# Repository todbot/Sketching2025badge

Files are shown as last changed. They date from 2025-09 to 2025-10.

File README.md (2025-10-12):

# Sketching2025badge

Badge for Sketching in Hardware 2025

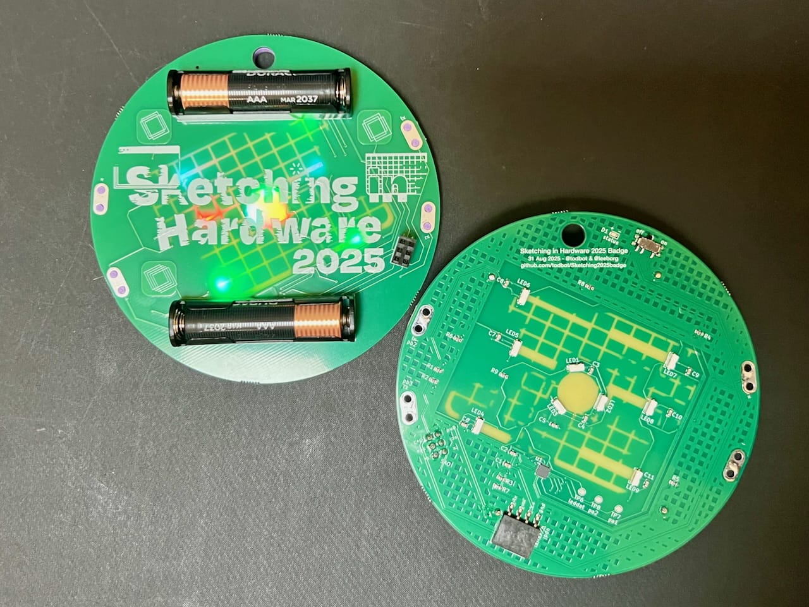
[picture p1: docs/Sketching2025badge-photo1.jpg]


sketching2025-badge-demoish-crop

# Features

- Three (3) capacitive touch pads
- Nine (9) "Neopixel"-compatible side-light RGB LEDs that shine through the back
- Four (4) sewable connectors: V+, Gnd, TX (PB2), and RX (PB3)
- One status LED on back of board
- Standard SAO pinout w/ I2C. Spare GPIO lines wired to UART TX/RX
- ATtiny816-based, same as [seesaw boards](https://learn.adafruit.com/adafruit-attiny817-seesaw)
- Easy compilation using standard Ardiuno toolchain and [megaTinyCore](https://github.com/SpenceKonde/megaTinyCore)
- Programmable with UDPI with a [USB-Serial adapter](https://amzn.to/3IKpMry)
- Uses modified [TouchyTouch](https://github.com/todbot/TouchyTouch) captouch library, included

# ATtiny816 pins used

| Use | GPIO | Arduino pin |
|---|---|---|
| Status LED | PB4 | 5 |
| Neopixel LEDs | PC2 | 12 |
| Touch pad 0 | PA6 | 0 |
| Touch pad 1 | PA5 | 1 |
| Touch pad 2 | PA4 | 2 |
| SAO I2C SCL | PB0 | 9 |
| SAO I2C SDA | PB1 | 8 |
| Sew / SAO UART TX | PB2 | 7 |
| Sew / SAO UART RX | PB3 | 6 |

# Reprogramming the badge

The default firmware is a fun little demo. But you can extend or replace it.

For details see [docs/firmware-install.md](docs/firmware-install.md)

But basically:
- Open up Arduino, add http://drazzy.com/package_drazzy.com_index.json
to the Board Manager URLs in Settings.
- Load "firmware/Sketching2025badge_attiny816/Sketching2025badge_attiny816.ino"
- Set the chip & programmer settings as in firmware-install.md
- Upload code with "Sketch" -> "Upload Using Programmer"

# Protective "Backer"

Since the LEDs and MCU on the back don't have the protection of the battery
holders as standoffs, a 3d-printed "backer" is included with the badge.
It snaps onto the badge using the sewable holes.
It can be removed by lifting it out, if you want to sew the badge down or
otherwise use the sewable holes.

See the "enclosure" directory for STEP/STL to print your own.

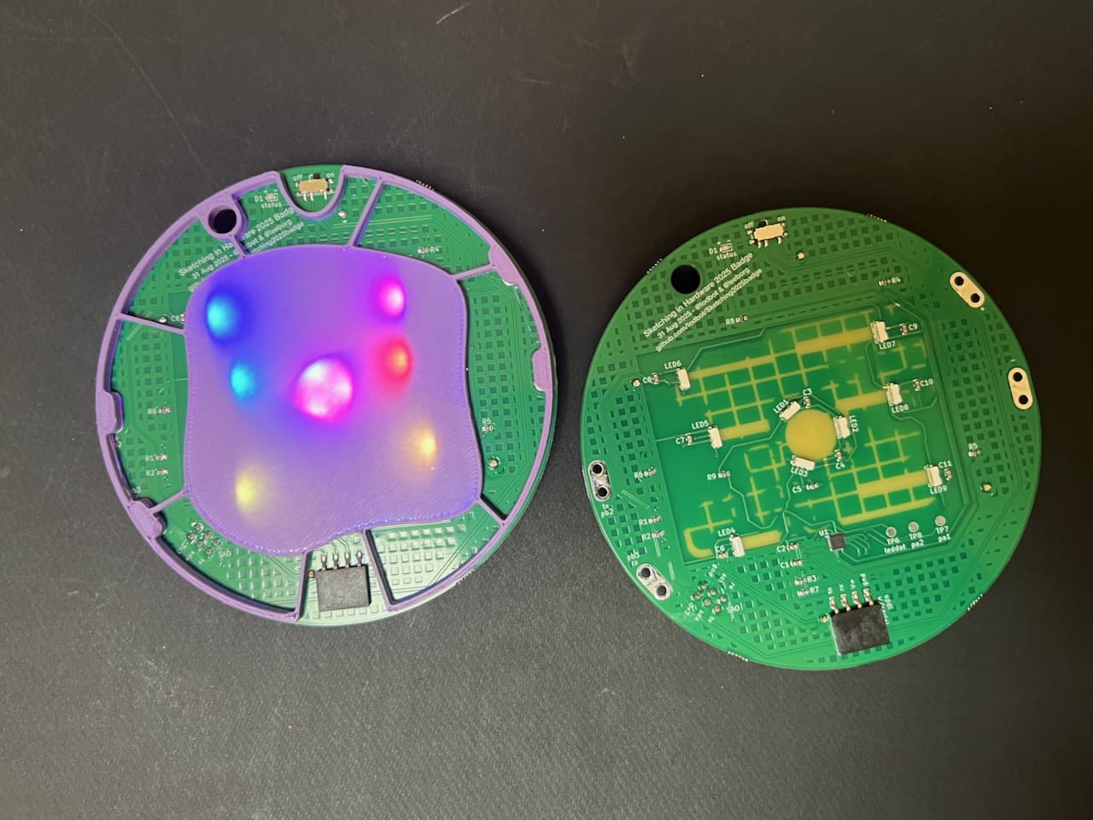
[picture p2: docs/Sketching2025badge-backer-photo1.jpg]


# Demos

* 30Aug2025 - Prototyp0 PCBA w/ batts on face, from JLC (with oops mask hole in center)

  https://github.com/user-attachments/assets/092c7233-f480-4e2a-861c-cc95c8bd24c3

# Renders

* 1 Oct 2025 - production version

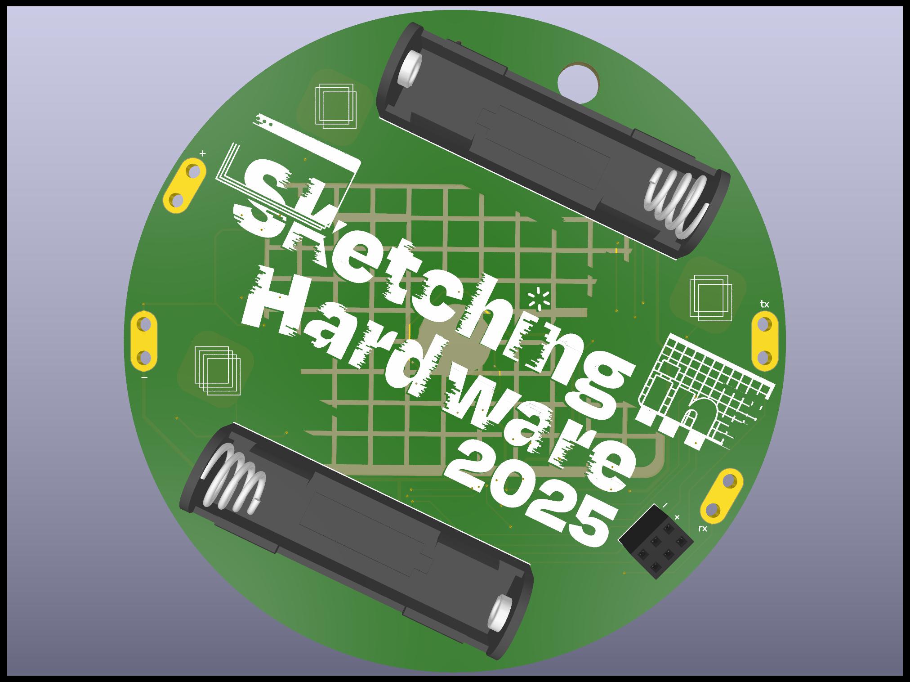
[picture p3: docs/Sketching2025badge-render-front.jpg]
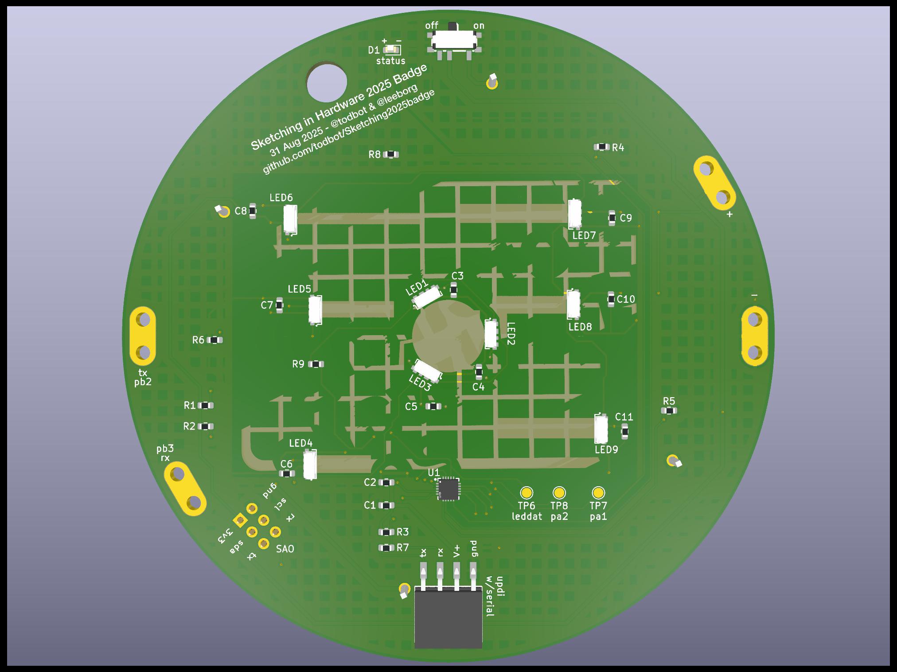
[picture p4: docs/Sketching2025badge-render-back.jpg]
  

* 16Aug2025 - Render0 - refaced TouchWheelSAO, basic graphics layout on 100mm (4") circular PCB, all components on back, routing incomplete

  https://github.com/user-attachments/assets/017a1953-9797-4b04-9c11-582e099e5368

* 16Aug2026 - Render0a - same as above, but with AAA holders on top

  https://github.com/user-attachments/assets/b0e8170d-4cca-4846-9cb0-e9c19dae7c72

# Schematic

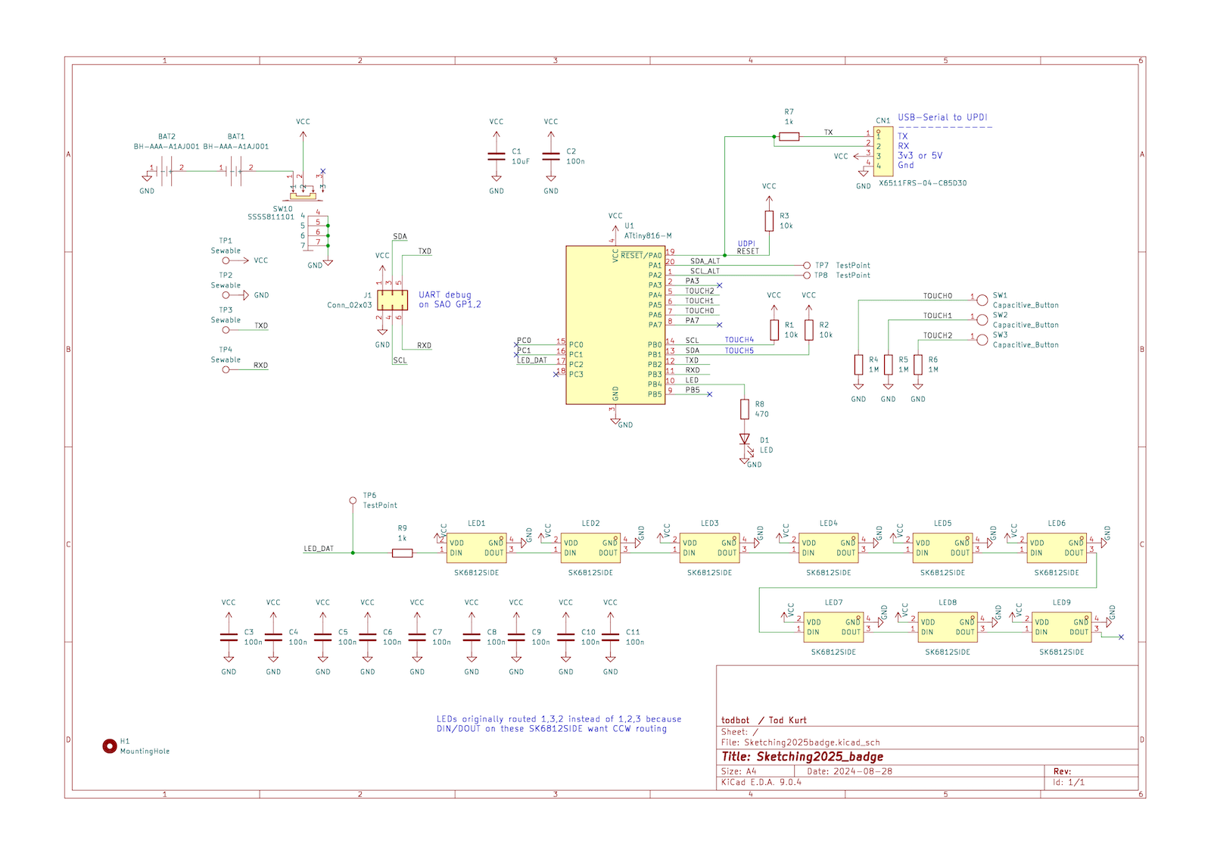
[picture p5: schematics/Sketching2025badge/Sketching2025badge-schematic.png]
Sketching 2025 badge schematic


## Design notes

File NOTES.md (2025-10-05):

## Notes:

* 1 Oct 2025 - 48 badges mailed to Paris
  - 20 had backers
  - still printing remainders

* 29 Sep 2025 - Design & print protective "backer"
  - Design for "fast" printing (~30 min each on my old Prusa mk2.5s)
  - Start batch 3D printing

* 29 Sep 2025 - "final" firmware cutoff
  - batch program begin
  - programmed 50 production boards
  - all boards passed basic programming & lighting test

* 23 Sep 2025 - Badge PCBAs received from JLC
  - delivered from JLC via UPS
  - badge final assembly: hand solder battery holder & SAO header

* 11 Sep 2025 - PCBAs ordered
  - PCBway wanted $1k for badges, even with sponsorship
  - Ordered JLCPCB instead $344 (inc. shipping & tariffs)

* 30 Aug 2025 - tested prototype0
  - All parts seem functional, both at 5V of programmer & 3V of AA batteries
  - Idle current: 15 mA at 10 MHz, 10 mA at 8 MHz
  - Don't set to 4 MHz, it doesn't work. LEDs go all white (drawing 300mA)
  - To-Do:
    - edit light mask polygons on back to be wider
    - move LEDs out from under battery holder
    - change UDPI prog footprint to female SMD RA header socket

* 24 Aug 2025 - prototype0 sent to JLC, with "21 Aug 2025" datestamp

* 16 Aug 2025 - basic graphics import test, got okay from leeborg

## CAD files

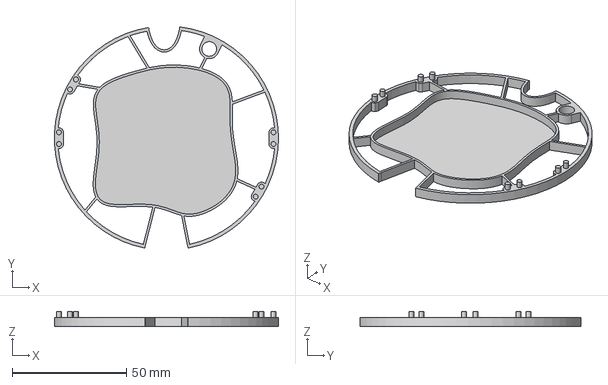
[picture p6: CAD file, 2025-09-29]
enclosure/Sketching2025badge_backing.step
97.9 x 96.7 x 6.50 mm

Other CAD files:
enclosure/Sketching2025badge_backing.stl

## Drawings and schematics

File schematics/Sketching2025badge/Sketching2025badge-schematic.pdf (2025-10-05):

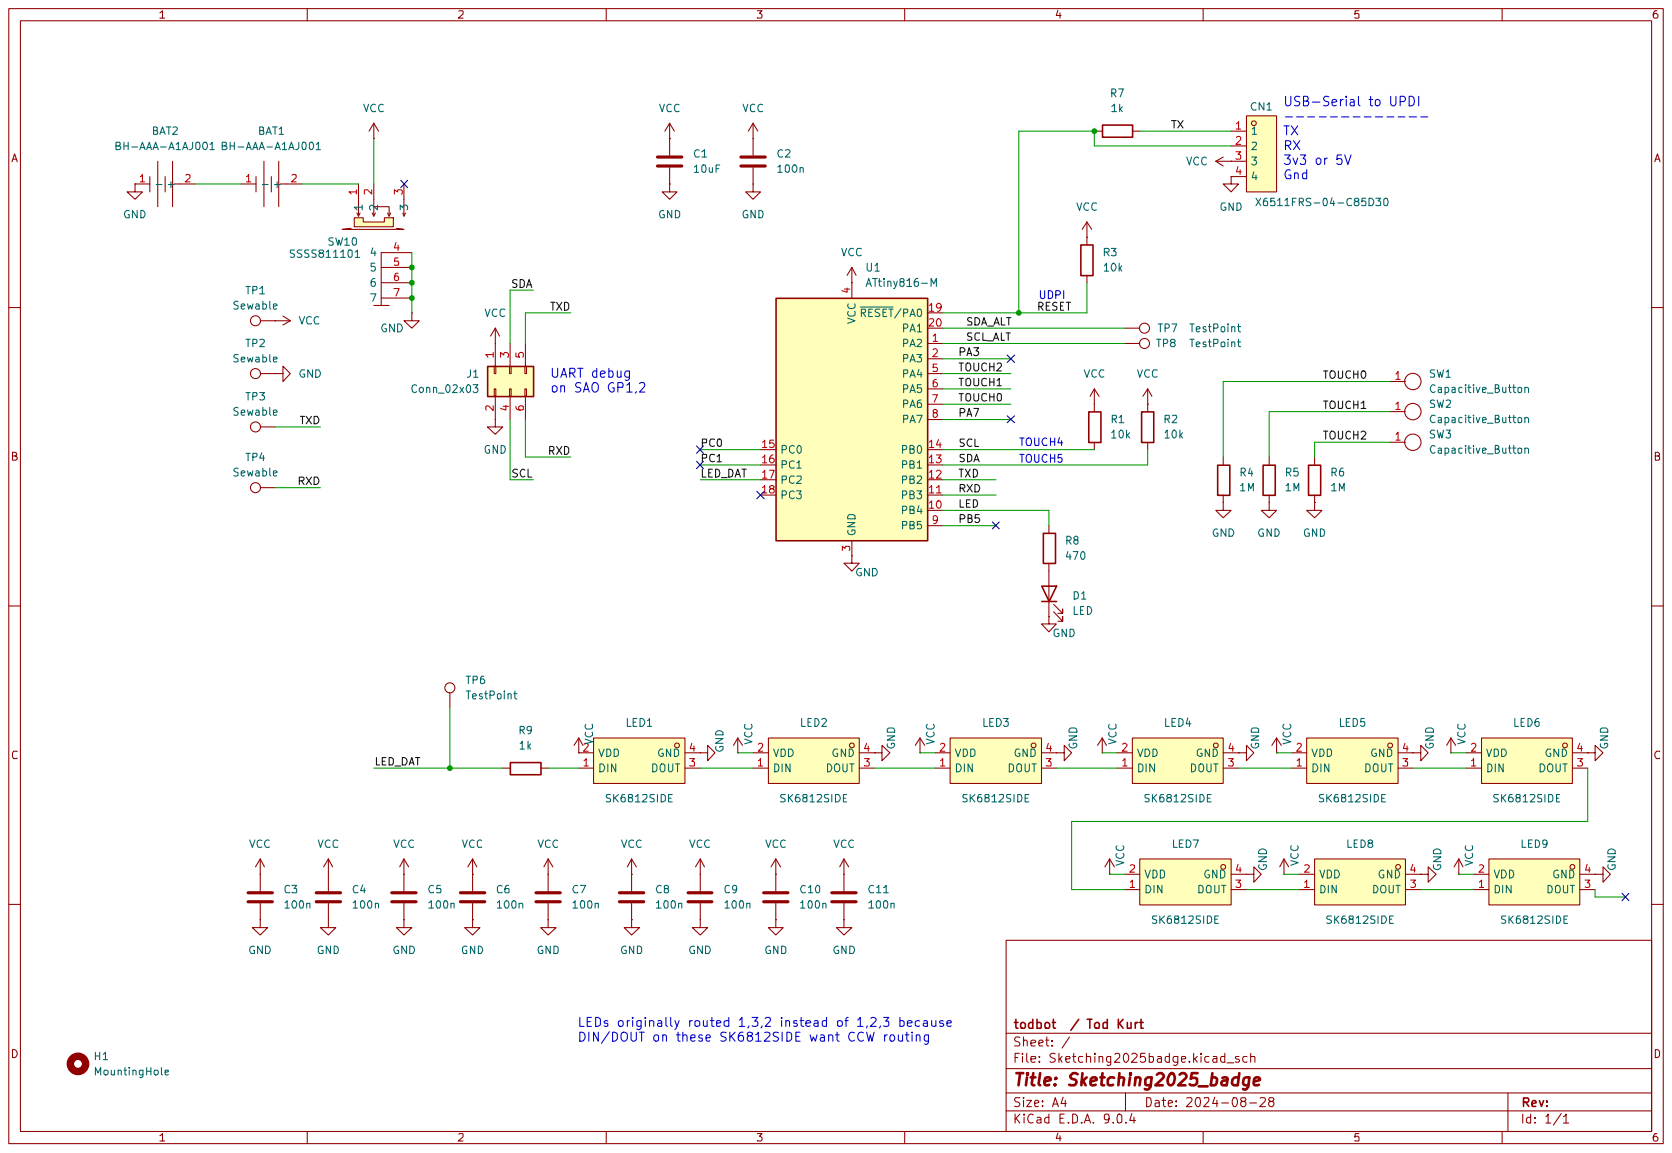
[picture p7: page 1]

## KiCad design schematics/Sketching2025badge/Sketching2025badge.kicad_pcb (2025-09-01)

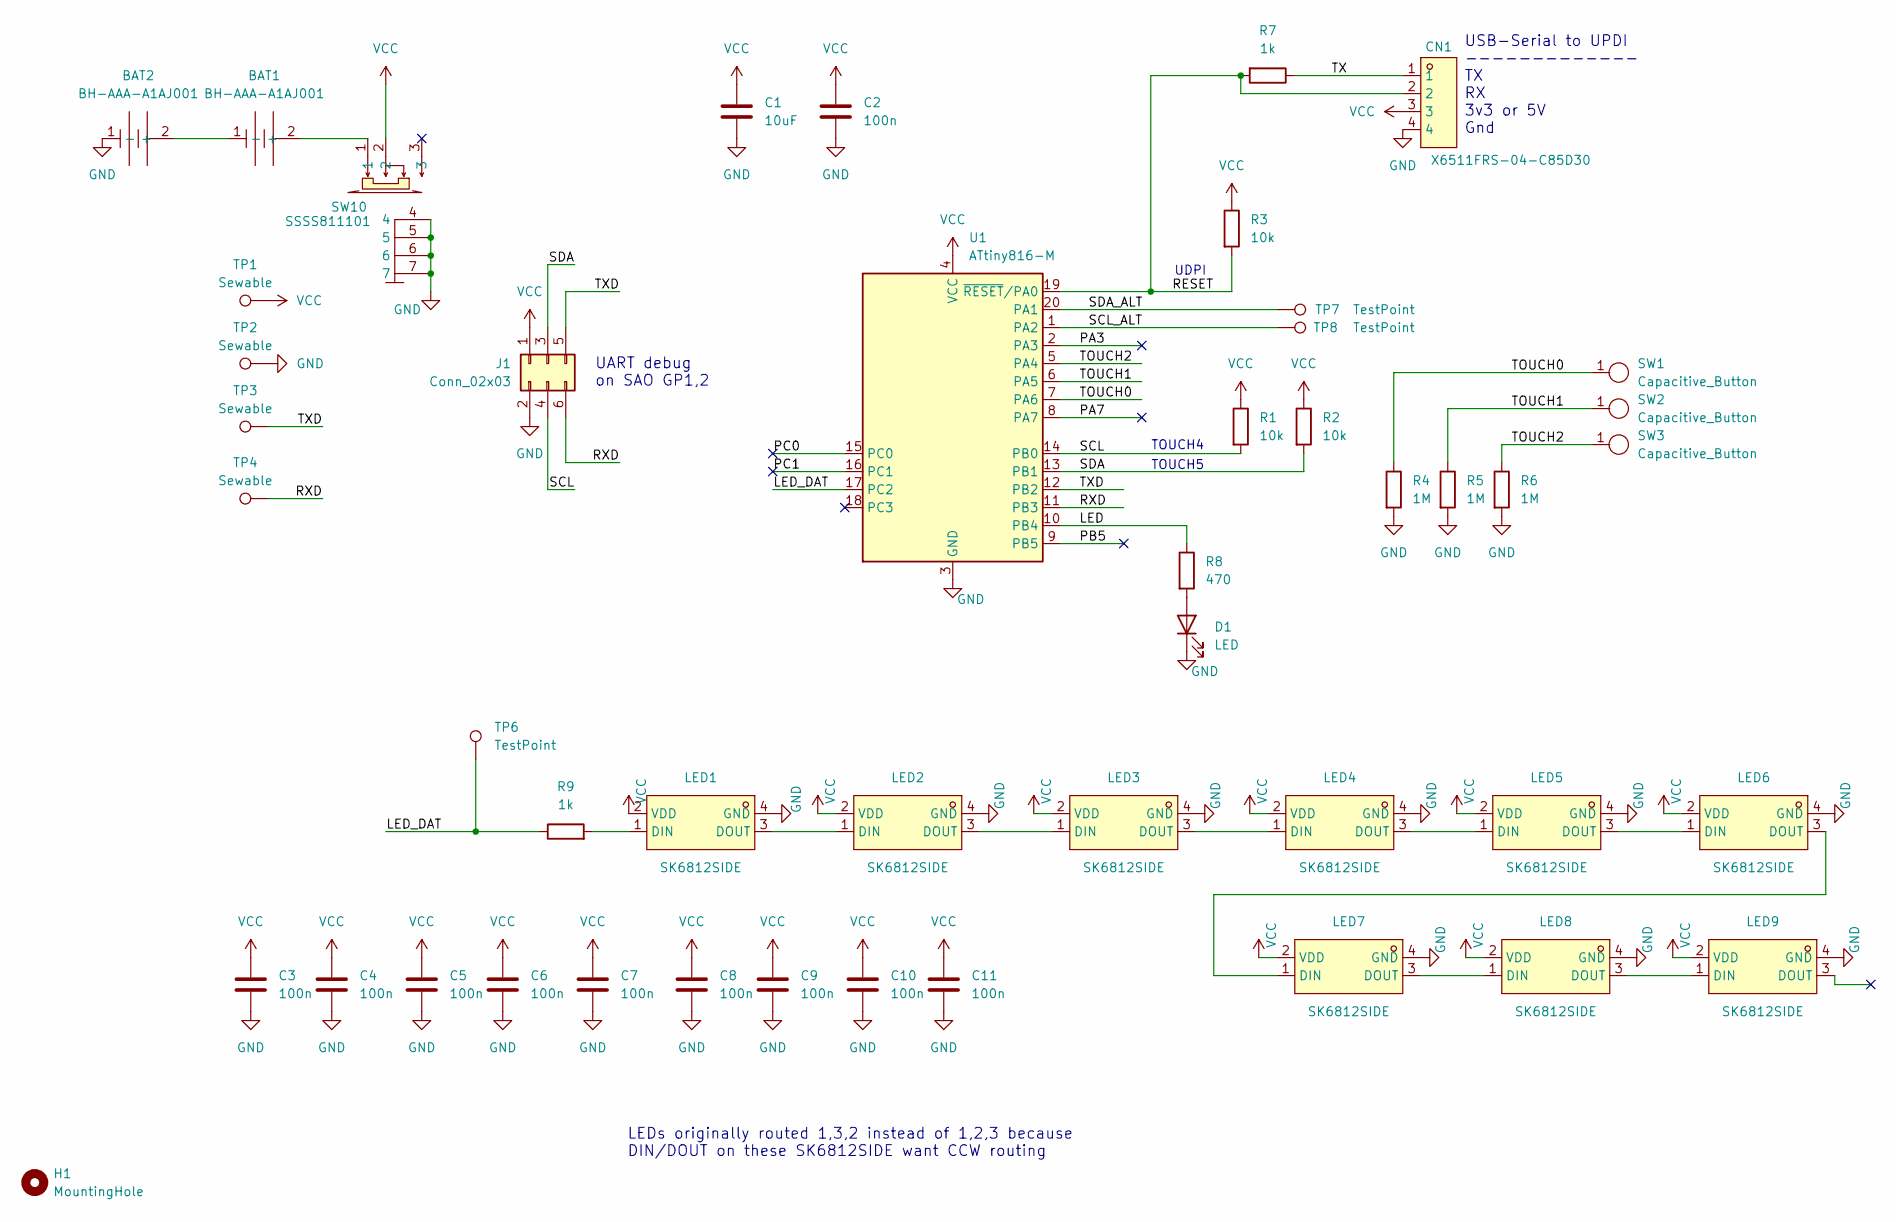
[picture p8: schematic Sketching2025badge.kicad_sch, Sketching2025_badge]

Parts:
BAT1, BAT2: BH-AAA-A1AJ001; BAT-TH_BH-AAA-A1AJ001; LCSC Part C5290189
C1: 10uF; R_0603_1608Metric; LCSC Part C434425
C2, C3, C4, C5, C6, C7, C8, C9, C10, C11: 100n; R_0603_1608Metric; LCSC Part C1590
CN1: X6511FRS-04-C85D30; HDR-SMD_4P-P2.54-H-F; LCSC Part C5142237
D1: LED; LED_0603_1608Metric; LCSC Part C434425
H1: MountingHole; MountingHole_6.4mm_M6
J1: Conn_02x03; PinSocket_2x03_P2.54mm_Vertical; Part Number LL1009-2A, 2.54MM 2*3PIN HEADER,LENGTH=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; LCSC Part C541853
LED1, LED2, LED3, LED4, LED5, LED6, LED7, LED8, LED9: SK6812SIDE; LED-SMD_4P-L4.0-W1.6-L; LCSC Part C5378721
R1, R2, R3: 10k; R_0603_1608Metric
R4, R5, R6: 1M; R_0603_1608Metric
R7, R9: 1k; R_0603_1608Metric
R8: 470; R_0603_1608Metric
SW1, SW2, SW3: Capacitive_Button; Pad-CapTouch-10mm-roundrect-nosilk
SW10: SSSS811101; SW-SMD_SSSS811101; LCSC Part C109335
TP1, TP2, TP3, TP4: Sewable; Lilypad-BUTTONHOLE
TP6, TP7, TP8: TestPoint; TestPoint_Pad_D1.5mm
U1: ATtiny816-M; UQFN-20_L3.0-W3.0-P0.40-BL-EP1.7; LCSC Part C2052778

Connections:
/LED: R8.1, U1.10 (PB4)
/LED_DAT: R9.1, TP6.1, U1.17 (PC2)
/PA3: U1.2 (PA3)
/PA7: U1.8 (PA7)
/PB5: U1.9 (PB5)
/PC0: U1.15 (PC0)
/PC1: U1.16 (PC1)
/RESET: CN1.2, R3.2, R7.2, U1.19 (~RESET/PA0)
/RXD: J1.6 (GND), TP4.1, U1.11 (PB3)
/SCL: J1.4 (GND), R1.2, U1.14 (PB0)
/SCL_ALT: TP8.1, U1.1 (PA2)
/SDA: J1.3 (GND), R2.2, U1.13 (PB1)
/SDA_ALT: TP7.1, U1.20 (PA1)
/TOUCH0: R4.1, SW1.1 (A), U1.7 (PA6)
/TOUCH1: R5.1, SW2.1 (A), U1.6 (PA5)
/TOUCH2: R6.1, SW3.1 (A), U1.5 (PA4)
/TX: CN1.1, R7.1
/TXD: J1.5 (GND), TP3.1, U1.12 (PB2)
GND: BAT2.1 (-), C1.2, C2.2, C3.2, C4.2, C5.2, C6.2, C7.2, C8.2, C9.2, C10.2, C11.2, CN1.4, D1.1 (K), J1.2 (+12V), LED1.4 (GND), LED2.4 (GND), LED3.4 (GND), LED4.4 (GND), LED5.4 (GND), LED6.4 (GND), LED7.4 (GND), LED8.4 (GND), LED9.4 (GND), R4.2, R5.2, R6.2, SW10.4, SW10.5, SW10.6, SW10.7, TP2.1, U1.3 (GND), U1.21 (GND)
unnamed: BAT1.2 (+), SW10.1
unnamed: BAT1.1 (-), BAT2.2 (+)
unnamed: D1.2 (A), R8.2
unnamed: LED1.1 (DIN), R9.2
unnamed: LED1.3 (DOUT), LED2.1 (DIN)
unnamed: LED2.3 (DOUT), LED3.1 (DIN)
unnamed: LED3.3 (DOUT), LED4.1 (DIN)
unnamed: LED4.3 (DOUT), LED5.1 (DIN)
unnamed: LED5.3 (DOUT), LED6.1 (DIN)
unnamed: LED6.3 (DOUT), LED7.1 (DIN)
unnamed: LED7.3 (DOUT), LED8.1 (DIN)
unnamed: LED8.3 (DOUT), LED9.1 (DIN)
VCC: C1.1, C2.1, C3.1, C4.1, C5.1, C6.1, C7.1, C8.1, C9.1, C10.1, C11.1, CN1.3, J1.1 (+12V), LED1.2 (VDD), LED2.2 (VDD), LED3.2 (VDD), LED4.2 (VDD), LED5.2 (VDD), LED6.2 (VDD), LED7.2 (VDD), LED8.2 (VDD), LED9.2 (VDD), R1.1, R2.1, R3.1, SW10.2, TP1.1, U1.4 (VCC)

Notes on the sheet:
LEDs originally routed 1,3,2 instead of 1,2,3 because DIN/DOUT on these SK6812SIDE want CCW routing
TOUCH5
TOUCH4
UART debug on SAO GP1,2
USB-Serial to UPDI ------------- TX RX 3v3 or 5V Gnd
UDPI

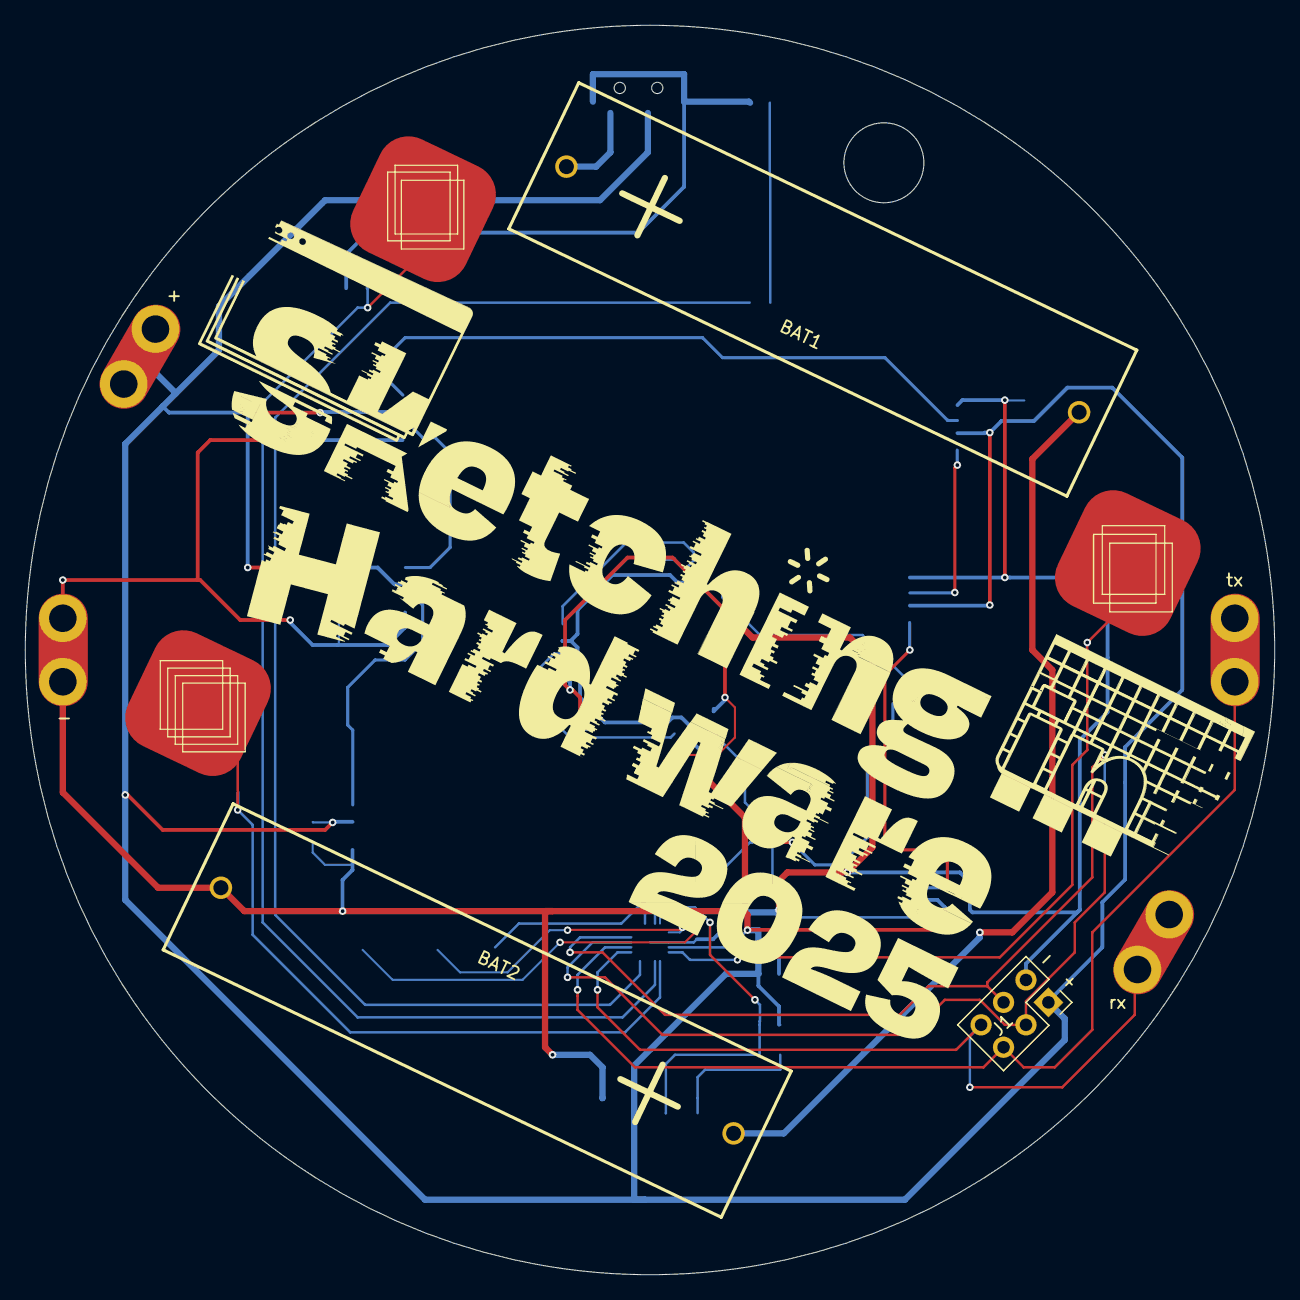
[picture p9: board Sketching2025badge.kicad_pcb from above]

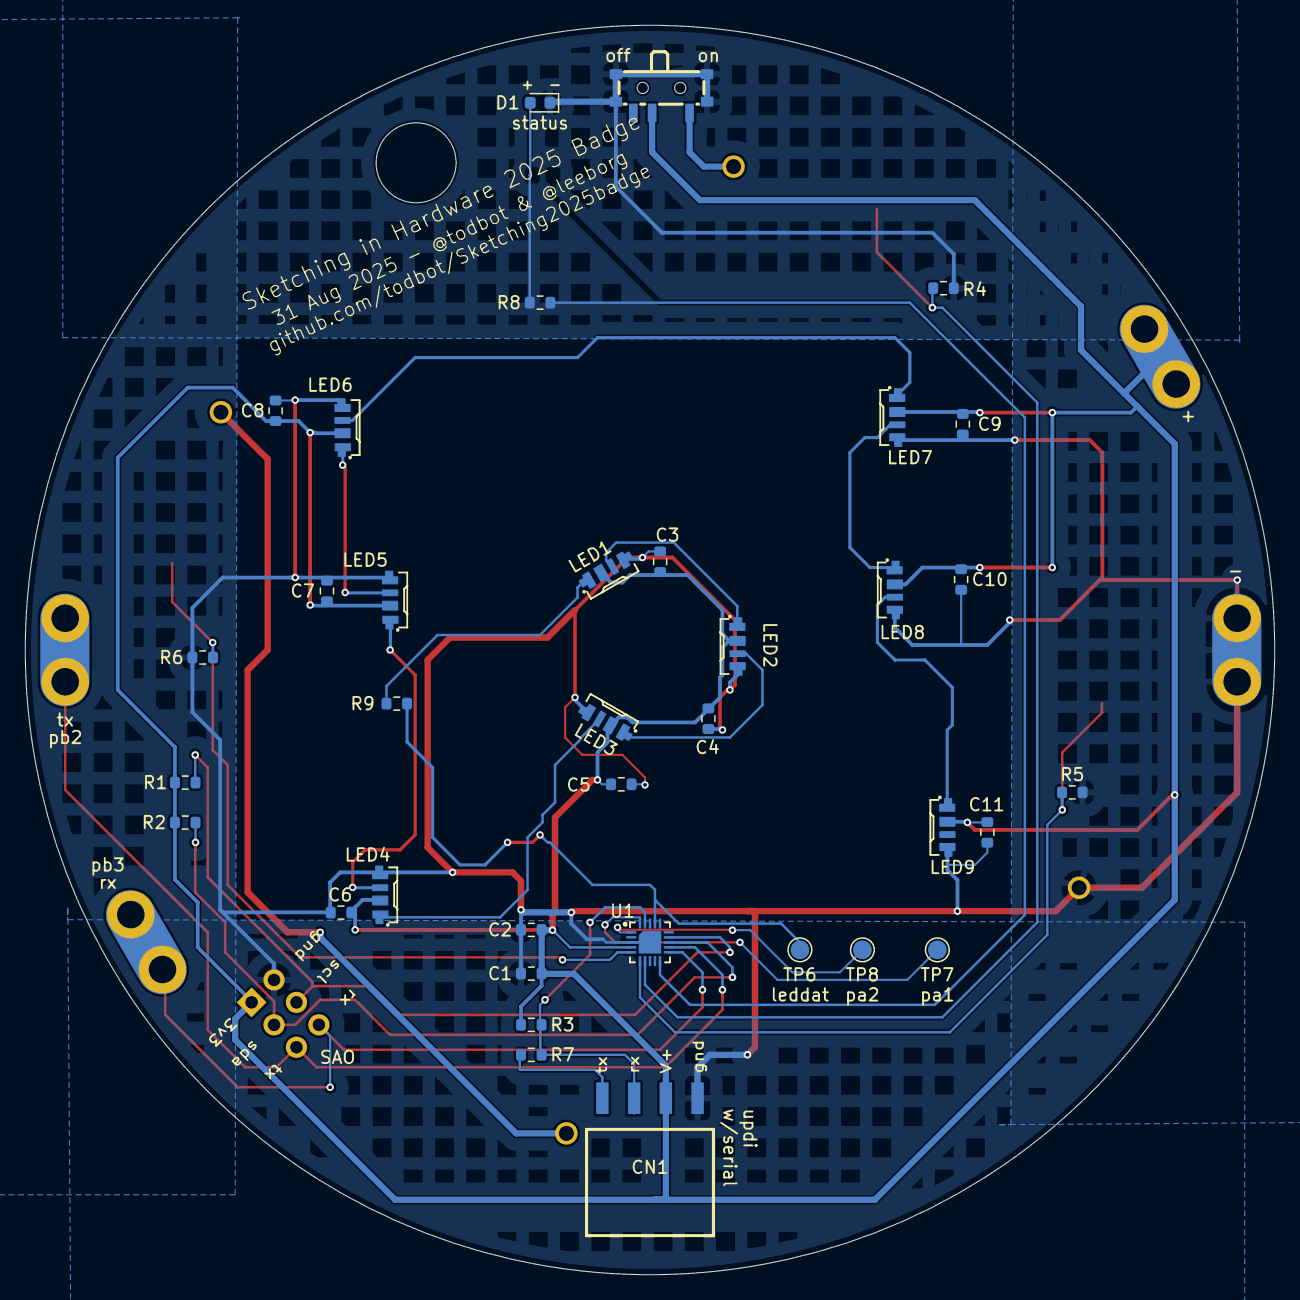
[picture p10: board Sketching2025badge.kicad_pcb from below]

Board: 2 copper layers, 100.0 x 100.0 mm, 47 parts (40 on the bottom side), 27 nets.

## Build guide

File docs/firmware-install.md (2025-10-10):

# Installing firmware on Sketching2025badge board

Use any Windows, MacOS, Linux, RaspberryPi host with USB-to-serial adapter.

## Hardware prep

The Sketching2025badge board has the UPDI programming port brought out as a 4-pin
SMD header, which a 4-pin pin header can be soldered, or a 4-pin 0.1" spacing
pogo-pin jig clamp can be attached.

The pins on the TouchWheelSAO board are laid out for use with a
[USB-to-serial adapter wired as a UPDI programmer](https://learn.adafruit.com/adafruit-attiny817-seesaw/advanced-reprogramming-with-updi)
but you can also use a standard UPDI programmer too.

Here is what a programmer setup could look like, using:
* [cheap USB-to-serial dongle](https://amzn.to/47sMaxz)
* [Pogo pin probe clip](https://www.digikey.com/short/3c99n5p9)

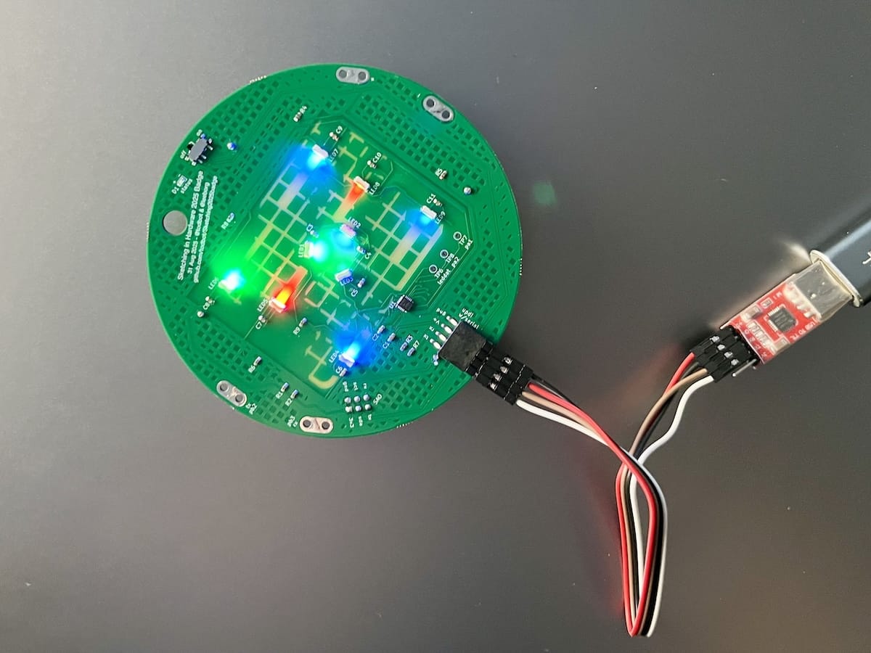
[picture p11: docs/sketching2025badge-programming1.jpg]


## Software, Compiling, Uploading

### GUI IDE install

If installing with the Arduino GUI, you need to install the latest Arduino IDE 
from [arduino.cc/en/software/](https://www.arduino.cc/en/software/#ide).

The badge is based on the AVR ATtiny816 chip.  
This is supported by the [megaTInyCore](https://github.com/SpenceKonde/megaTinyCore) 
In the Arduino IDE, add this core by going to Settings / Additional Board Manager URLs and 
add `http://drazzy.com/package_drazzy.com_index.json` to the list. 
Then in Boards Manager, add "megaTinyCore".

Pick the board type in Tools / Board as "megaTinyCore" -> "ATtiny3226/3216/../816/../406"

In the Tools menu, set the chip parameters as:

- Chip: "ATtiny816"
- Clock: "8 MHz internal"
- Printf: "minimal"
- Programmer: "Serial UDPI - SLOW 57600" or "Serial UDPI - 230400"
- (leave everything else as default)

When uploading, use "Upload Using Programmer" instead of the normal "Upload".

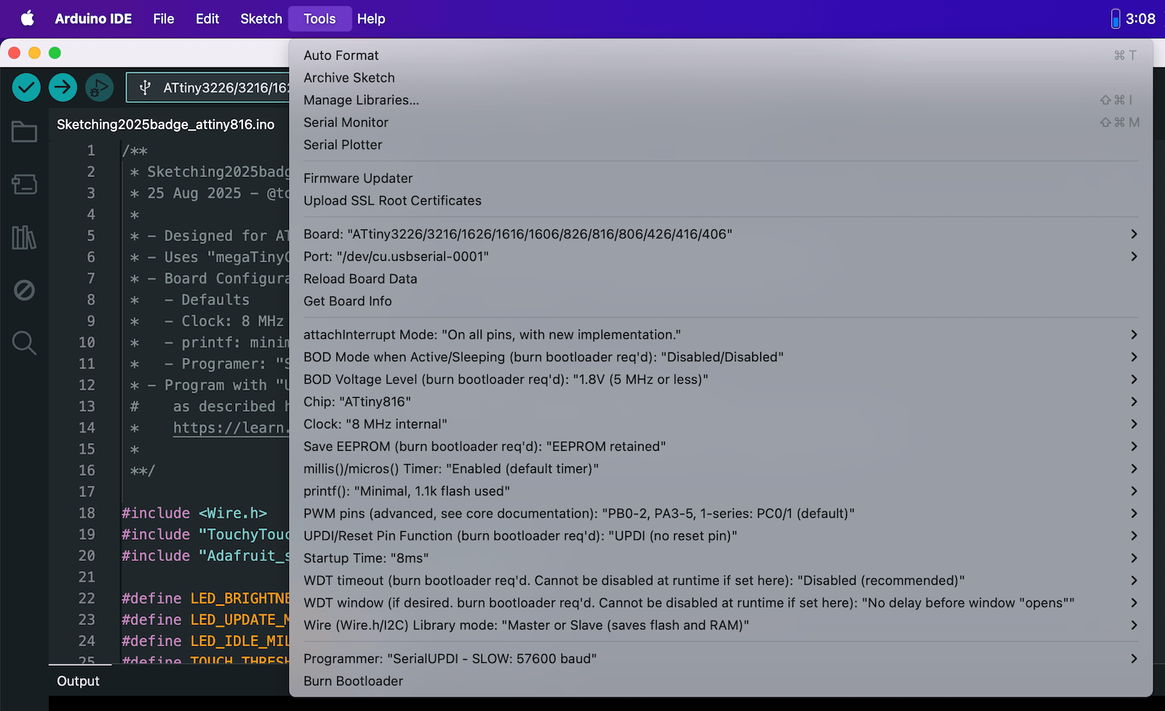
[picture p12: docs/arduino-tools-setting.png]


### Arduino-CLI install

Instead of installing the Arduino IDE, we can also use [arduino-cli](https://arduino.github.io/arduino-cli/1.0/)

#### Install arduino-cli

The [arduino-cli install page](https://arduino.github.io/arduino-cli/1.0/installation/#latest-release)
has pre-built binaries for common platforms.  And if on MacOS, you can do `brew install arduino-cli`

#### Install megatinycore 

The badge uses the ATtiny816 chip.  This is supported by the MegaTinyAVR core. 

```sh
arduino-cli core install megatinycore:megaavr  --additional-urls https://drazzy.com/package_drazzy.com_index.json
 ```

#### Show some details on the core (optional):

```sh
arduino-cli board details -b megaTinyCore:megaavr:atxy6
```

#### Compile:

```sh
arduino-cli compile --verbose --fqbn megaTinyCore:megaavr:atxy6:chip=816,printf=minimal,clock=8internal \
            --build-path=$(pwd)/build Sketching2025badge_attiny816
```

#### Upload

```sh
arduino-cli upload --verbose --fqbn megaTinyCore:megaavr:atxy6:chip=816  \
            --port /dev/ttyUSB0 --programmer serialupdi57k  \
            --input-dir ./build

```

#### Shell script for batch programming

Also see `firmware/batch_build_program.sh`

```sh
#!/bin/bash

PORT=/dev/ttyUSB0
HEX_FILE=./build/Sketching2025badge_attiny816.ino.hex

while [ 1 ] ; do
  read -rsn1 -p"Press any key program firmware"; echo
  arduino-cli upload --verbose --fqbn megaTinyCore:megaavr:atxy6:chip=816  \
              --port $PORT --programmer serialupdi57k  \
              --input-file=$HEX_FILE
  echo "--------------------"
done

```

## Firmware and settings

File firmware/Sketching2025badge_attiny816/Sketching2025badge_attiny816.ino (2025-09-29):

/**
 * Sketching2025badge_attiny816.ino -- 
 * 25 Aug 2025 - @todbot / Tod Kurt
 * 
 * - Designed for ATtiny816
 * - Uses "megaTinyCore" Arduino core: https://github.com/SpenceKonde/megaTinyCore/
 * - Board Configuration in Tools:
 *   - Defaults
 *   - Clock: 8 MHz internal
 *   - printf: minimal
 *   - Programer: "SerialUPDI - SLOW 57600 baud" or "SerialUPDI - 230400"
 * - Program with "Upload with Programmer" with a USB-Serial dongle 
 #    as described here: 
 *    https://learn.adafruit.com/adafruit-attiny817-seesaw/advanced-reprogramming-with-updi
 * 
 **/

#include <Wire.h>
#include "TouchyTouch.h"
#include "Adafruit_seesawPeripheral_tinyneopixel.h"

#define LED_BRIGHTNESS  80         // range 0-255, used by pixel_funcs.hs
#define LED_UPDATE_MILLIS (15)     // how often to update the LEDs, affects fade down time
#define LED_IDLE_MILLIS (30*1000)  // 30 seconds
#define TOUCH_THRESHOLD_ADJ (1.2)

// note these pin numbers are the megatinycore numbers: 
// https://github.com/SpenceKonde/megaTinyCore/blob/master/megaavr/variants/txy6/pins_arduino.h
#define LED_STATUS_PIN  5 // PB4
#define NEOPIXEL_PIN 12  // PC2
#define MySerial Serial
#define NUM_LEDS (9)

#include "pixel_funcs.h"

const int touch_pins[] = {0, 1, 2, };  // which pins are the touch pins
const int touch_count = sizeof(touch_pins) / sizeof(int);
TouchyTouch touches[touch_count];
volatile uint8_t led_buf[NUM_LEDS*3];  // RGB LEDs: 3 bytes per LED

uint32_t last_debug_time;
uint32_t last_led_time;
uint32_t last_touch_millis = 0;  // last time any touch was pressed
uint16_t fade_timer = 0;
uint8_t r,g,b;
uint8_t pos = 0;  // color wheel position
uint8_t touched = 0;  // bit-field of touches
bool held = false;   // is a touch held (any touch)
bool do_startup_demo = true;



// ---------------------------------------------------------------------------
// setup
void setup() {
  MySerial.begin(115200);
  MySerial.println("\r\nWelcome to Sketching2025!");
  
  pinMode(LED_STATUS_PIN, OUTPUT);
  pinMode(NEOPIXEL_PIN, OUTPUT);

  // touch buttons
  for (int i = 0; i < touch_count; i++) {
    touches[i].begin( touch_pins[i] );
    touches[i].threshold = touches[i].raw_value * TOUCH_THRESHOLD_ADJ; // auto threshold doesn't work
  }
}

void touch_recalibrate() {
    for(int i=0; i< touch_count; i++) { 
      uint16_t v = touches[i].recalibrate();
      touches[i].threshold = v * TOUCH_THRESHOLD_ADJ; // auto threshold doesn't work
    }
}

// update touch input state
// must be called within a block that's timed (like if(now-update_millis))
void update_touch(uint32_t now) { 
  uint8_t touched_last = touched;
  touched = 0;
  for (int i = 0; i < touch_count; i++) {
    touches[i].update();
    touched |= (touches[i].touched() << i);
  }

  if (touched) {
    fade_timer = 0;
    if (touched != touched_last) { 
      last_touch_millis = now;  // record when touch changed
    }
    if (now - last_touch_millis > 500) { 
      held = true;  // note held if touched more than 0.5 secs
    }
  }
  else {  // on release
    held = false;
    fade_timer = 1000;
  }
}

void pattern_colorwheel(uint8_t pos, uint8_t wheel_step=50) {
  for(uint8_t n=0; n<NUM_LEDS; n++) { 
    colorwheel(pos + n*wheel_step, &r, &g, &b);
    pixel_set(n, r,g,b);
  }
}

void pattern_sparkles(uint8_t pos) {
  pixel_fade_all(3);
  //r = 225; g = 25; b = 160; // a warmer white, sorta, but fades bad
  r = g = b = 225;
  if (pos%16 == 0 ) {  // slow it down
    pixel_set(pos%NUM_LEDS, r,g,b);
  }
}

void pattern_whitespin(uint8_t pos) {
  r  = g = b = 200; 
  for(uint8_t n=0; n < 3; n++) { 
    pixel_set(n, r,g,b);
    if (pos%3 == n) { 
      pixel_set(n, 0,0,0); // turn one of them off to emulate spinning
    }
  }
}

void pattern_colorwheel_demo(uint16_t delay_ms=5) {
  for( int i=0; i<255; i++) {
    pattern_colorwheel(pos++);
    pixel_show();
    delay(delay_ms);
  }
}

// ---------------------------------------------------------------------------
// main loop
void loop() {

  if(do_startup_demo) { 
    pattern_colorwheel_demo();
    touch_recalibrate();  // recalibrate in case pads touched on power up or unstable power
    do_startup_demo = false;
    fade_timer = 1000;
  }
  
  // LED update
  uint32_t now = millis();

  if( now - last_led_time > LED_UPDATE_MILLIS ) {  // only update neopixels every N msec
    last_led_time = now;

    update_touch(now);   // updates toucheed and touches[] 

    digitalWrite(LED_STATUS_PIN, held ? HIGH : LOW);  // simple held status indicator

    if (now - last_touch_millis > LED_IDLE_MILLIS) { // idle timer expired, let's sparkle
      last_touch_millis = now;
      for( int i=0; i< 10; i++) { 
        pixel_fill(i*6, i*3, i*6);
        pixel_show();
        delay(100);
      }
      pattern_colorwheel_demo();
    }
    
    // show how to handle touch "pressed" events
    //   start at a different location on the colorwheel depending on button
    if (touches[0].pressed()) {       // button 0  (top right)
      pos = 0;
    }
    else if (touches[1].pressed()) {  // button 1  (bottom left)
      pixel_fill(0,0,0);
    }
    else if (touches[2].pressed()) {  // button 2 (top left)
    }

    // act on touch state
    if (touched) {
      if (held) { 
        pos++;  // while held, rotate "pos" value for color wheel or other uses
      }
      if( touched == 0b100 ) {         // button 2 pressed (top left)
        pos++;                         // gives the sense of it 'revving up'
        pattern_whitespin(pos/4);      // the /4 slows down the spinning;
      }
      else if( touched == 0b010 ) {    // button 1 pressed (bottom left)
        pattern_colorwheel(pos, 100);  // play pattern on touch
      }
      else if( touched == 0b001 ) {    // button 0 pressed (top right)
        pos++;  
        pattern_sparkles(pos);         // play pattern on touch
      }
    }
    else {  // if not touched
      // fade down LEDs on release
      if( fade_timer ) { 
        fade_timer--;
        pixel_fade_all(1);
      }
    }

    pixel_show();
  }

  //debug
  // if( now - last_debug_time > 100 ) { 
  //   last_debug_time = now;
  //   MySerial.printf("pos: %d %d\r\n", pos, touched);
  // }

} // loop()


// RGB colorwheel, just for Tom Igoe
// Input a value 0 to 255 to get a color value.
// The colours are a transition r - g - b - back to r.
// pass in pointers to three bytes: r,g,b to set them
void colorwheel(byte wheelPos, uint8_t* pr, uint8_t* pg, uint8_t* pb ) {
  wheelPos = 255 - wheelPos;
  if (wheelPos < 85) {
    *pr = 255 - wheelPos * 3;  *pg = 0;  *pb = wheelPos * 3;
  }
  else if (wheelPos < 170) {
    wheelPos -= 85;
    *pr = 0; *pg = wheelPos * 3, *pb = 255 - wheelPos * 3;
  }
  else { 
    wheelPos -= 170;
    *pr = wheelPos * 3; *pg = 255 - wheelPos*3, *pb = 0;
  }
}

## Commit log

2025-08-21 almost routed, difficult getting through the maze of the B.Mask
    [Sketching2025badge.kicad_pcb, Sketching2025badge.kicad_sch]
2025-08-22 first version routed, not pass drc yet
    [Sketching2025badge.kicad_pcb, Sketching2025badge.kicad_sch]
2025-08-22 routed, mostly pass drc
    [Sketching2025badge.kicad_pcb, Sketching2025badge.kicad_sch]
2025-08-24 added bypass caps and switch
    [Sketching2025badge.kicad_pcb, Sketching2025badge.kicad_sch]
2025-08-24 first version to production
    [Sketching2025badge.kicad_pcb, Sketching2025badge.kicad_sch]
2025-08-30 verify jlc test run1
    [Sketching2025badge.kicad_pcb]
2025-08-31 moved to female prog header, widened mask polygons for more light
    [Sketching2025badge.kicad_pcb, Sketching2025badge.kicad_sch]
2025-08-31 Update README.md with prototype0 demo video
2025-08-31 minor fixups to pcb
    [Sketching2025badge.kicad_pcb]
2025-09-01 update with prelim version sent to PCBWay
    [Sketching2025badge.kicad_pcb]
2025-09-29 add backing STL and STEP
    [Sketching2025badge_backing.step, Sketching2025badge_backing.stl]
2025-10-10 Document Arduino-CLI installation process
    Added section for Arduino-CLI installation as an alternative to Arduino IDE.
